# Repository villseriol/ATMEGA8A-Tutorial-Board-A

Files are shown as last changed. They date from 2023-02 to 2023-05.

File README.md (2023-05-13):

# ATMEGA8A Tutorial Board A

| Revision | Description |
| --- | --- |
| 1.0 | <ul><li>Completed initial design of evaluation board.</li></ul> |
| 1.1 | <ul><li>Added series resistor to external reset for MCU.</li><li>Added series resistor to potentiometer for short-circuit protection.</li><li>Added series resistor to NE555 output for short-circuit protection.</li><li>Updated ISP-10 footprint to ISP-6.</li><li>Updated resistor footprint.</li></ul> |
| 1.2 | <ul><li>Added company logo to top silkscreen.</li><li>Changed vertical DIP switch to horizontal.</li></ul> |

## Getting Started

### Prerequisites

```bash
# install build tools
sudo apt-get install binutils gcc-avr avr-libc uisp avrdude flex byacc bison
```

### Building

Execute the following commands in the `software-design` folder,

#### USBasp

```bash
# Windows 10
cmake --preset default
cmake --build . --preset default
# Ubuntu
cmake --preset default
cmake --build --preset default
```

#### AVRISP MKII

```bash
# Windows 10
cmake --preset avrispii
cmake --build . --preset avrispii
# Ubuntu
cmake --preset avrispii
cmake --build --preset avrispii
```

### Targets

After building the `default` preset the following targets will be made available in the generated makefile,

```bash
# flash command for a simple blink program
make flash-blink-sync
make disassemble-blink-sync

# enables the use of an external 16MHz clock source
make fuse
```

## Modules

### 7 Segment

| Diagram | Description |
| --- | --- |
|  | <ul><li>The 7-segment display uses all of Port D for setting the individual segments</li><li>The lower nibble of Port C is used to multiplex the currently active digit</li><li>The digits are numbered from left to right when the decimal point is positioned correctly relative to the users point of view</li><li>All segments and selection pins are active low</li></ul> |

| Microcontroller | D0  | D1  | D2  | D3  | D4  | D6  | D7  | C0 | C1 | C2 | C3 |
| --- | --- | --- | --- | --- | --- | --- | --- | --- | --- | --- | --- |
| 7-segment | F | C | A | G | B | E | DEC | Digit 1 | Digit 2 | Digit 3 | Digit 4 |

| Value | D7  | D6  | D5  | D4  | D3  | D2  | D1  | D0  | HEX  |
| ----- | --- | --- | --- | --- | --- | --- | --- | --- | ---- |
| 0 | 1 | 0 | 0 | 0 | 1 | 0 | 0 | 0 | 0x88 |
| 1 | 1 | 1 | 1 | 0 | 1 | 1 | 0 | 1 | 0xED |
| 2 | 1 | 0 | 0 | 0 | 0 | 0 | 1 | 1 | 0x83 |
| 3 | 1 | 1 | 0 | 0 | 0 | 0 | 0 | 1 | 0xC1 |
| 4 | 1 | 1 | 1 | 1 | 0 | 1 | 0 | 0 | 0xE4 |
| 5 | 1 | 1 | 0 | 1 | 1 | 0 | 0 | 0 | 0xD0 |
| 6 | 1 | 0 | 0 | 1 | 1 | 0 | 0 | 0 | 0x90 |
| 7 | 1 | 1 | 1 | 0 | 1 | 0 | 0 | 1 | 0xE9 |
| 8 | 1 | 0 | 0 | 0 | 0 | 0 | 0 | 0 | 0x80 |
| 9 | 1 | 1 | 1 | 0 | 0 | 0 | 0 | 0 | 0xE0 |

### LED

Two active high LEDs located on pins B1 and B2 of the microcontroller.

### Potentiometer

A 50k linear potentiometer connected to pin C4. The potentiometer has two 1K resistors in series for current limiting & protection. It is expected that the analog readout on the potentiometer will never reach GND or VCC (but will come close).

### Timer

The NE555 chip feeds into the input capture pin (B0) of the microcontroller. The output frequency ranges from 100Hz~1000Hz by setting the individual DIP switches.

## Specifications

### Rev 1.0

| Top | Bottom |
| --- | --- |
| Board Top Layer | Board Bottom Layer |

### Rev 1.1

| Top | Bottom |
| --- | --- |
| Board Top Layer | Board Bottom Layer |

### Rev 1.2

| Top | Bottom |
| --- | --- |
| Board Top Layer | Board Bottom Layer |

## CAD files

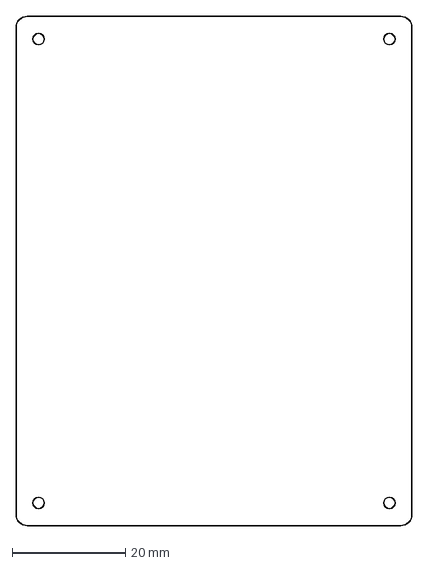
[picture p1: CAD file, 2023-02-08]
electrical-design/PCB Edge.dxf
70.0 x 90.0 mm

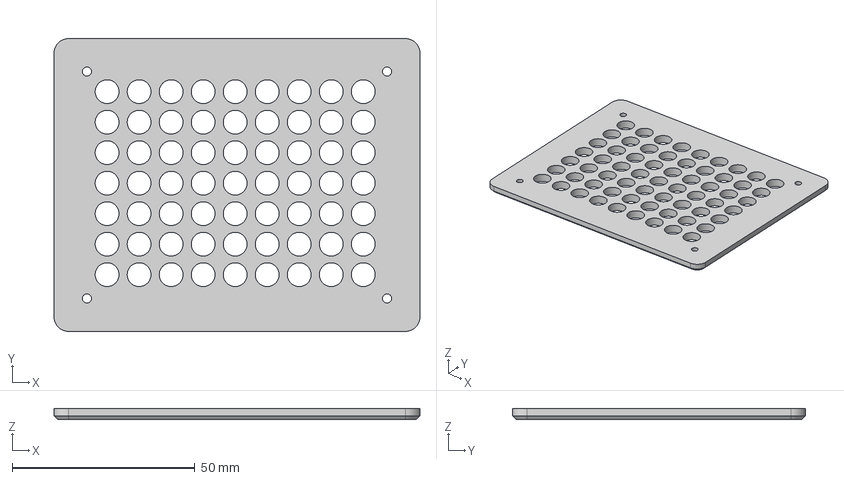
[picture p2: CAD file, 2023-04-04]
mechanical-design/A-00.step
100.0 x 80.0 x 3.00 mm

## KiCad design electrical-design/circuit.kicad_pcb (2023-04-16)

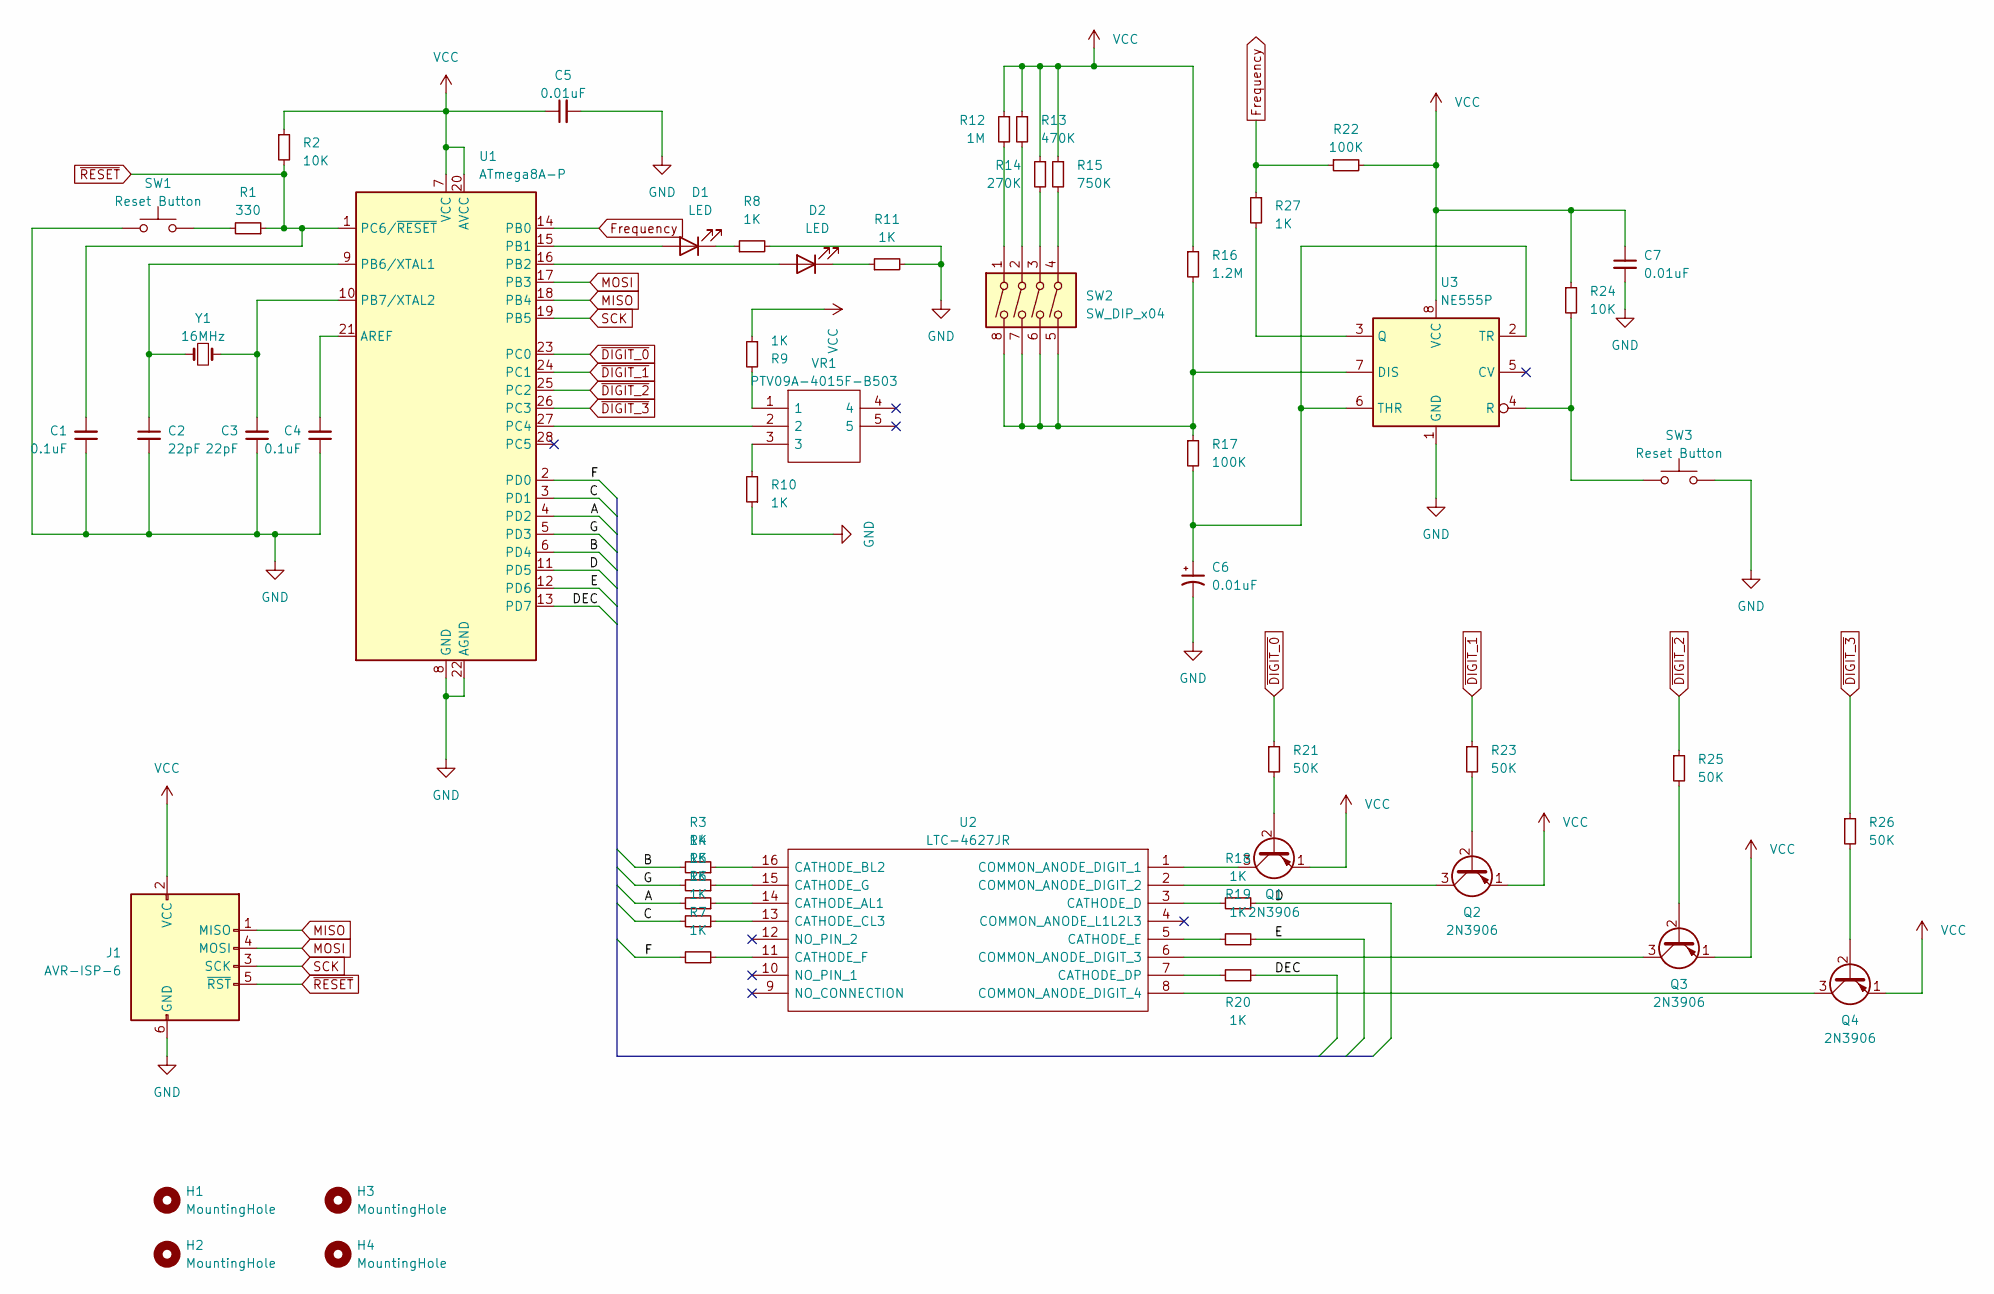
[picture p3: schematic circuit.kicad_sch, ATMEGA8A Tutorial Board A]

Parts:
C1, C4: 0.1uF; C_Disc_D3.0mm_W2.0mm_P2.50mm
C2, C3: 22pF; C_Disc_D3.0mm_W2.0mm_P2.50mm
C5, C6, C7: 0.01uF; C_Disc_D3.0mm_W2.0mm_P2.50mm
D1, D2: LED; LED_D3.0mm
H1, H2, H3, H4: MountingHole; MountingHole_2.2mm_M2_DIN965_Pad_TopBottom
J1: AVR-ISP-6; PinHeader_2x03_P2.54mm_Vertical
Q1, Q2, Q3, Q4: 2N3906; TO-92_Inline
R1: 330; R_Axial_DIN0207_L6.3mm_D2.5mm_P7.62mm_Horizontal
R2, R24: 10K; R_Axial_DIN0207_L6.3mm_D2.5mm_P7.62mm_Horizontal
R3, R4, R5, R6, R7, R8, R9, R10, R11, R18, R19, R20, R27: 1K; R_Axial_DIN0207_L6.3mm_D2.5mm_P7.62mm_Horizontal
R12: 1M; R_Axial_DIN0207_L6.3mm_D2.5mm_P7.62mm_Horizontal
R13: 470K; R_Axial_DIN0207_L6.3mm_D2.5mm_P7.62mm_Horizontal
R14: 270K; R_Axial_DIN0207_L6.3mm_D2.5mm_P7.62mm_Horizontal
R15: 750K; R_Axial_DIN0207_L6.3mm_D2.5mm_P7.62mm_Horizontal
R16: 1.2M; R_Axial_DIN0207_L6.3mm_D2.5mm_P7.62mm_Horizontal
R17, R22: 100K; R_Axial_DIN0207_L6.3mm_D2.5mm_P7.62mm_Horizontal
R21, R23, R25, R26: 50K; R_Axial_DIN0207_L6.3mm_D2.5mm_P7.62mm_Horizontal
SW1: Reset Button; SW_PUSH_6mm
SW2: SW_DIP_x04; SW_DIP_SPSTx04_Slide_9.78x12.34mm_W7.62mm_P2.54mm
SW3: Reset Button; SW_PUSH_6mm_H5mm
U1: ATmega8A-P; DIP-28_W7.62mm_Socket
U2: LTC-4627JR; DIPS1016W50P254L4018H725Q16N; Mouser Part Number 859-LTC-4627JR
U3: NE555P; DIP-8_W7.62mm_Socket
VR1: PTV09A-4015F-B503; PTV09A4020FB103; Mouser Part Number 652-PTV09A-4015FB503
Y1: 16MHz; Crystal_HC49-4H_Vertical

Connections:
/A: R5.2, U1.4 (PD2)
/B: R3.2, U1.6 (PD4)
/C: R6.2, U1.3 (PD1)
/D: R18.1, U1.11 (PD5)
/DEC: R20.1, U1.13 (PD7)
/E: R19.1, U1.12 (PD6)
/F: R7.2, U1.2 (PD0)
/G: R4.2, U1.5 (PD3)
Frequency: R22.1, R27.1, U1.14 (PB0)
GND: C1.1, C2.2, C3.1, C4.1, C5.2, C6.2, C7.2, J1.6 (GND), R8.2, R10.1, R11.2, SW1.1, SW3.2, U1.8 (GND), U1.22 (AGND), U3.1 (GND)
MISO: J1.1 (MISO), U1.18 (PB4)
MOSI: J1.4 (MOSI), U1.17 (PB3)
unnamed: D1.2 (A), U1.15 (PB1)
unnamed: D1.1 (K), R8.1
unnamed: D2.2 (A), U1.16 (PB2)
unnamed: D2.1 (K), R11.1
unnamed: Q1.2 (B), R21.2
unnamed: Q1.3 (C), U2.1 (COMMON_ANODE_DIGIT_1)
unnamed: Q2.2 (B), R23.2
unnamed: Q2.3 (C), U2.2 (COMMON_ANODE_DIGIT_2)
unnamed: Q3.2 (B), R25.2
unnamed: Q3.3 (C), U2.6 (COMMON_ANODE_DIGIT_3)
unnamed: Q4.2 (B), R26.2
unnamed: Q4.3 (C), U2.8 (COMMON_ANODE_DIGIT_4)
unnamed: R1.2, SW1.2
unnamed: R9.2, VR1.1
unnamed: R10.2, VR1.3
unnamed: R12.2, SW2.1
unnamed: R13.2, SW2.2
unnamed: R14.2, SW2.3
unnamed: R15.2, SW2.4
unnamed: C4.2, U1.21 (AREF)
unnamed: C2.1, U1.9 (PB6/XTAL1), Y1.2
unnamed: C3.2, U1.10 (PB7/XTAL2), Y1.1
unnamed: U1.27 (PC4), VR1.2
unnamed: R5.1, U2.14 (CATHODE_AL1)
unnamed: R3.1, U2.16 (CATHODE_BL2)
unnamed: R6.1, U2.13 (CATHODE_CL3)
unnamed: R18.2, U2.3 (CATHODE_D)
unnamed: R20.2, U2.7 (CATHODE_DP)
unnamed: R19.2, U2.5 (CATHODE_E)
unnamed: R7.1, U2.11 (CATHODE_F)
unnamed: R4.1, U2.15 (CATHODE_G)
unnamed: R16.2, R17.1, SW2.5, SW2.6, SW2.7, SW2.8, U3.7 (DIS)
unnamed: R27.2, U3.3 (Q)
unnamed: R24.2, SW3.1, U3.4 (R)
unnamed: C6.1, R17.2, U3.2 (TR), U3.6 (THR)
SCK: J1.3 (SCK), U1.19 (PB5)
VCC: C5.1, C7.1, J1.2 (VCC), Q1.1 (E), Q2.1 (E), Q3.1 (E), Q4.1 (E), R2.1, R9.1, R12.1, R13.1, R14.1, R15.1, R16.1, R22.2, R24.1, U1.7 (VCC), U1.20 (AVCC), U3.8 (VCC)
~DIGIT_0: R21.1, U1.23 (PC0)
~DIGIT_1: R23.1, U1.24 (PC1)
~DIGIT_2: R25.1, U1.25 (PC2)
~DIGIT_3: R26.1, U1.26 (PC3)
~RESET: C1.2, J1.5 (~RST), R1.1, R2.2, U1.1 (PC6/~RESET)

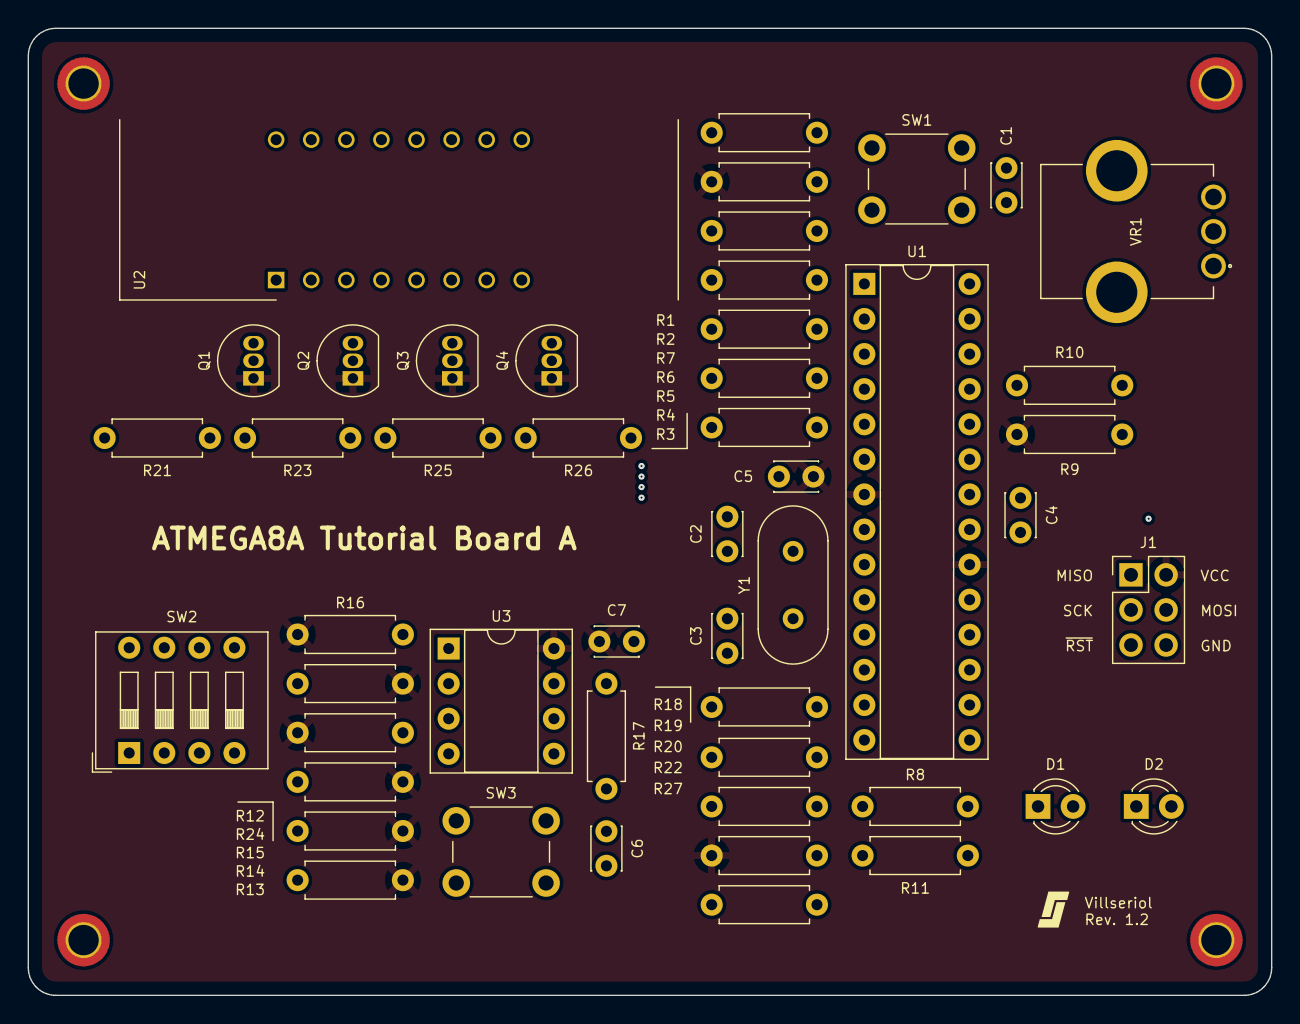
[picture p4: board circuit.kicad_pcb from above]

Board: 4 copper layers, 90.0 x 70.0 mm, 53 parts (0 on the bottom side), 54 nets.

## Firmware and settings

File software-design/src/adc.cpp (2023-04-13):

#define __AVR_ATmega8A__ ;

#include <avr/builtins.h>
#include <avr/interrupt.h>
#include <avr/io.h>
#include <util/delay.h>

#include "common.h"

namespace context
{
    volatile uint16_t adc = 0;
    volatile uint8_t digits[] = {0xFF, 0xFF, 0xFF, 0xFF};
    const uint8_t digits_size = sizeof(context::digits) / sizeof(*context::digits);
} // namespace context

void print(const uint16_t number)
{
    uint8_t buffer[] = {0xFF, 0xFF, 0xFF, 0xFF};
    const uint8_t buffer_size = sizeof(buffer) / sizeof(*buffer);
    common::uto7(number, buffer);

    for (uint8_t i = 0; i < buffer_size; i++)
    {
        context::digits[i] = buffer[i];
    }
}

int main(void)
{
    common::setup();

    __builtin_avr_cli();

    TIMSK |= _BV(TOIE0);
    TCCR0 = _BV(CS02);

    ADMUX = _BV(REFS0) | _BV(MUX2);
    ADCSRA = _BV(ADEN) | _BV(ADSC) | _BV(ADFR) | _BV(ADIE) | _BV(ADPS2) | _BV(ADPS1) | _BV(ADPS0);

    __builtin_avr_sei();

    while (1)
    {
        print(context::adc);
        _delay_ms(1000);
    }
}

ISR(TIMER0_OVF_vect)
{
    static uint8_t digit_selection_number = 0;

    const uint8_t mask = _BV(PC0) | _BV(PC1) | _BV(PC2) | _BV(PC3);
    const uint8_t digit_selection_mask = (PORTC | mask) & ~_BV(digit_selection_number);
    const uint8_t digit_selection_index = context::digits_size - digit_selection_number - 1;

    PORTD = context::digits[digit_selection_index];
    PORTC = digit_selection_mask;

    digit_selection_number = ++digit_selection_number % context::digits_size;
}

ISR(ADC_vect)
{
    context::adc = ADC;
}

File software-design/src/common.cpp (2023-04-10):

#include "common.h"

void common::setup()
{
    __builtin_avr_cli();

    DDRD = _BV(PD0) | _BV(PD1) | _BV(PD2) | _BV(PD3) | _BV(PD4) | _BV(PD5) | _BV(PD6) | _BV(PD7);
    DDRC = _BV(PC0) | _BV(PC1) | _BV(PC2) | _BV(PC3);
    DDRB = _BV(PB1) | _BV(PB2);

    // 7-segment and led's initially off
    PORTC |= _BV(PC0) | _BV(PC1) | _BV(PC2) | _BV(PC3);
    PORTD |= _BV(PD0) | _BV(PD1) | _BV(PD2) | _BV(PD3) | _BV(PD4) | _BV(PD5) | _BV(PD6) | _BV(PD7);
    PORTB &= ~(_BV(PB1) | _BV(PB2));

    __builtin_avr_sei();
}

void common::uto7(const uint16_t value, uint8_t *buffer)
{
    uint16_t quotient = value;
    uint16_t remainder = 0;

    do
    {
        remainder = quotient % 10;
        *buffer++ = pgm_read_byte(&common::SEVEN_SEGMENT_MAP[remainder]);
        quotient /= 10;
    } while (quotient > 0);
}

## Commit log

2023-02-05 Added Electrical Design of Evaluation Board
    [circuit.kicad_pcb, circuit.kicad_sch]
2023-02-06 Moving Away From Protoboard to Actual PCB Due to Production Complications
    [PCB Edge.dxf, circuit.kicad_pcb, circuit.kicad_sch]
2023-02-06 Added LED's to Board
    [circuit.kicad_pcb, circuit.kicad_sch]
2023-02-08 Completed Initial Design of Circuit Board
    [PCB Edge.dxf, circuit.kicad_pcb, circuit.kicad_sch]
2023-02-11 Added BOM
    [circuit.kicad_pcb]
2023-02-17 Commiting Missing Files
    [circuit.kicad_pcb]
2023-02-19 Added Production Files
    [circuit-B_Cu.gbr, circuit-B_Mask.gbr, circuit-B_Paste.gbr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]
2023-02-19 Approved Evaluation Board For Production
    [circuit-B_Cu.gbr, circuit-B_Mask.gbr, circuit-B_Paste.gbr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]
2023-02-24 Updated Top And Bottom SVG Images
    [circuit-B_Cu.gbr, circuit-B_Mask.gbr, circuit-B_Paste.gbr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]
2023-02-24 Completed Design For Rev 1.0
    [circuit-B_Cu.gbr, circuit-B_Mask.gbr, circuit-B_Paste.gbr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]
2023-02-25 Created Parts Order List And Modified PCB Rev 1.0 Accordingly
    [circuit-B_Cu.gbr, circuit-B_Mask.gbr, circuit-B_Paste.gbr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]
2023-03-02 Send R1.0 to Production
    [circuit.kicad_pcb, circuit.kicad_sch]
2023-03-02 Started Design For Rev 1.1
    [circuit.kicad_pcb, circuit.kicad_sch]
2023-03-04 Completed Build Pipeline For AVR Device
2023-03-05 Changed ISP-10 Footprint to ISP-6
    [circuit-B_Cu.gbr, circuit-B_Mask.gbr, circuit-B_Paste.gbr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]
2023-03-09 Updated THT Resistor Footprint
    [circuit-B_Cu.gbr, circuit-B_Mask.gbr, circuit-B_Paste.gbr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]
2023-03-11 Completed Version 1.1
    [circuit-B_Cu.gbr, circuit-B_Mask.gbr, circuit-B_Paste.gbr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]
2023-03-11 Updated Rev1.1 Images
    [circuit-B_Cu.gbr, circuit-B_Mask.gbr, circuit-B_Paste.gbr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]
2023-03-13 Added Input Protection on NE555 Timer
    [circuit-B_Cu.gbr, circuit-B_Mask.gbr, circuit-B_Paste.gbr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]
2023-04-03 Got Blink Working on Circuit Board
2023-04-04 Added Mechanical Design Folder
    [A-00.step, circuit.kicad_pcb]
2023-04-09 Added Timer Target
2023-04-10 Timer Now Starts at Zero
2023-04-13 Added ADC Example Code
2023-04-14 Completed Design of 1.2
    [circuit-B_Cu.gbr, circuit-B_Mask.gbr, circuit-B_Paste.gbr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]
2023-04-16 Made DIP Packages Use Socket
    [circuit-B_Cu.gbr, circuit-B_Mask.gbr, circuit-B_Paste.gbr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]
